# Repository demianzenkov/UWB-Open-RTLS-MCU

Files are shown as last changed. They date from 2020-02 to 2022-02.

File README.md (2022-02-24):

Source code for Open-RTLS nodes (anchor, tag) based on STM32 microcontrollers. 

Open-RTLS supports TWR and TDOA modes. 

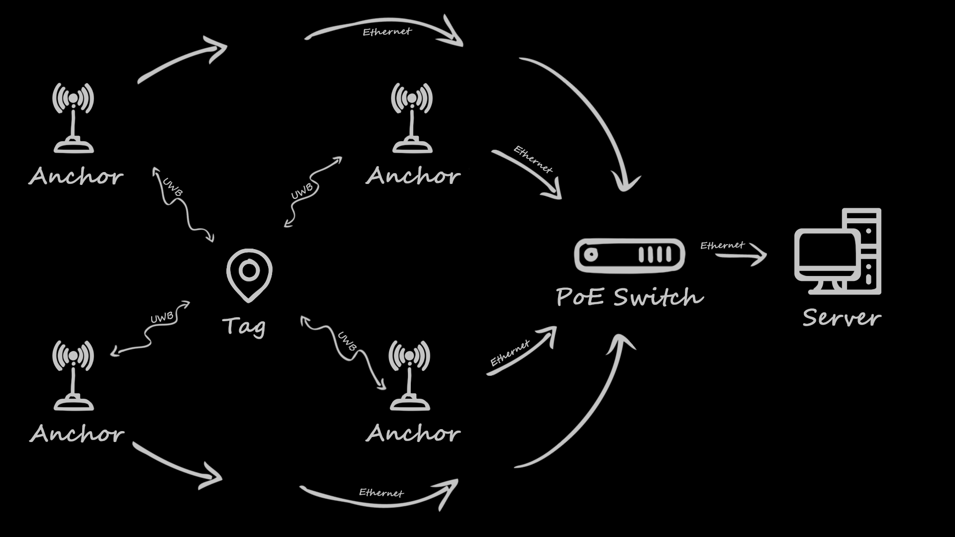
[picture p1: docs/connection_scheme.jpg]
connection_scheme
Communication scheme of RTLS units:

Anchor nodes are based on STM32F207 microcontrollers and have ethernet interface. Both anchors and tags have USB interface for connection with configuartion software.

To setup network and RTLS parameters of nodes use [Open-RTLS Configurator](https://github.com/DemianZ/UWB-Open-RTLS-Configurator).

##### Generate .c and .h proto files from .proto file using Nanopb:

```bash
pip install protobuf grpcio-tools
python proto/nanopb_generator.py -v proto/Settings.proto
```

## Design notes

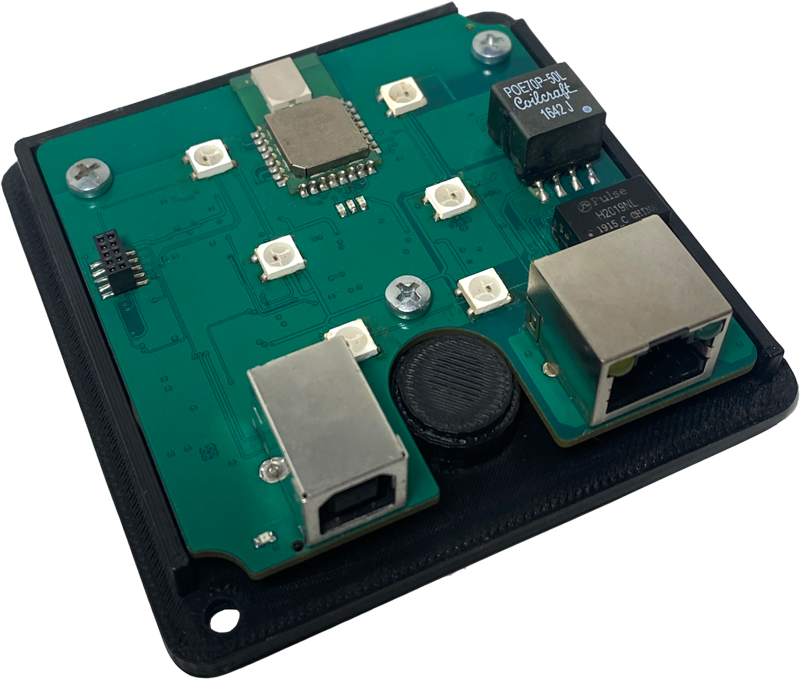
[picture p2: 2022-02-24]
hardware/anchor/Photos/anchor_no_cover.png

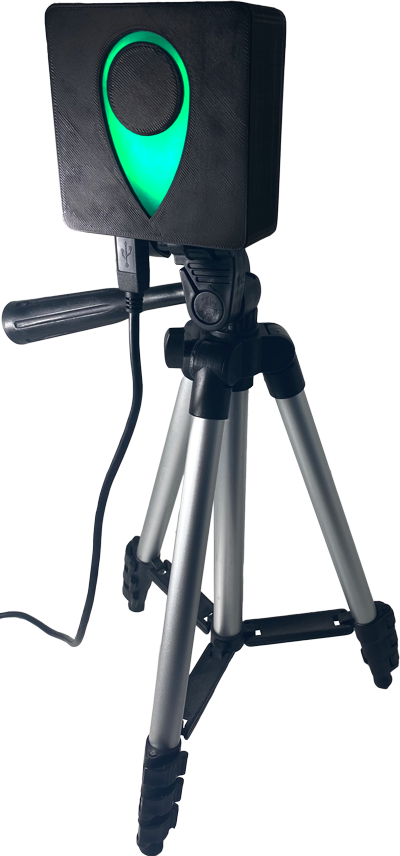
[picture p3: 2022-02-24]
hardware/anchor/Photos/anchor_shtativ.png

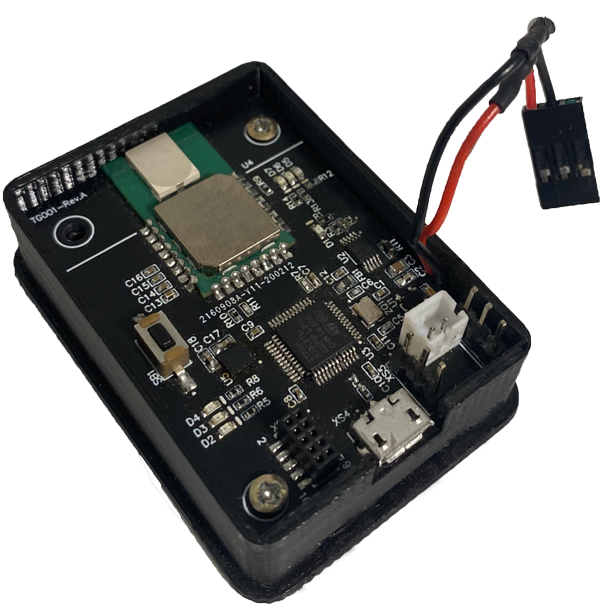
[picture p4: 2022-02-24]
hardware/anchor/Photos/tag_no_cover.png

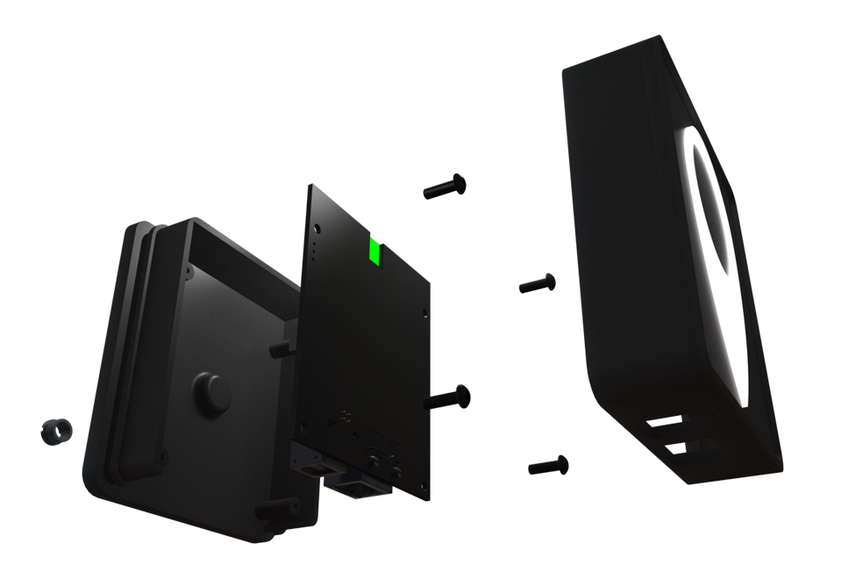
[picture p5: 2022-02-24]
hardware/anchor/Render/AN_01.png

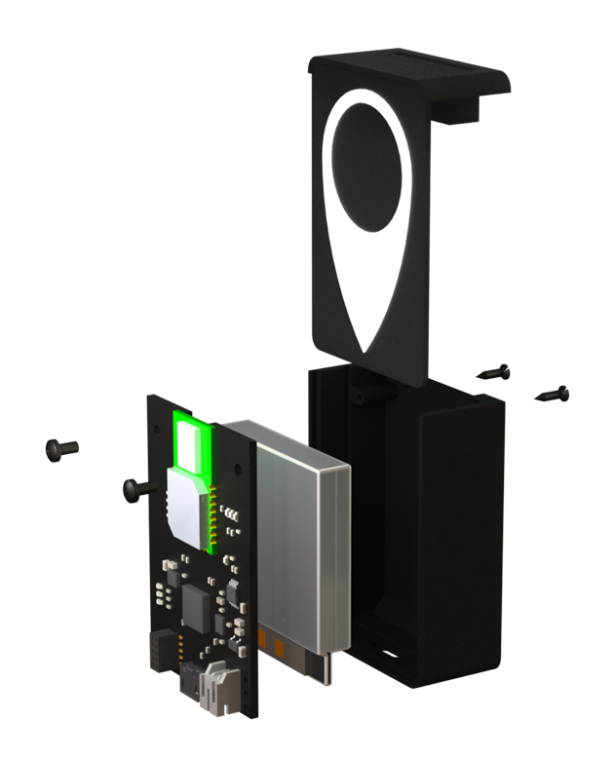
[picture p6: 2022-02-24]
hardware/anchor/Render/TG_02.png

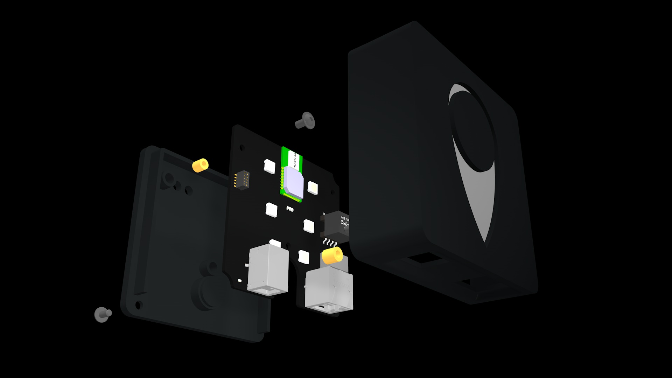
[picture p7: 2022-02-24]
hardware/anchor/Render/an_002.jpg

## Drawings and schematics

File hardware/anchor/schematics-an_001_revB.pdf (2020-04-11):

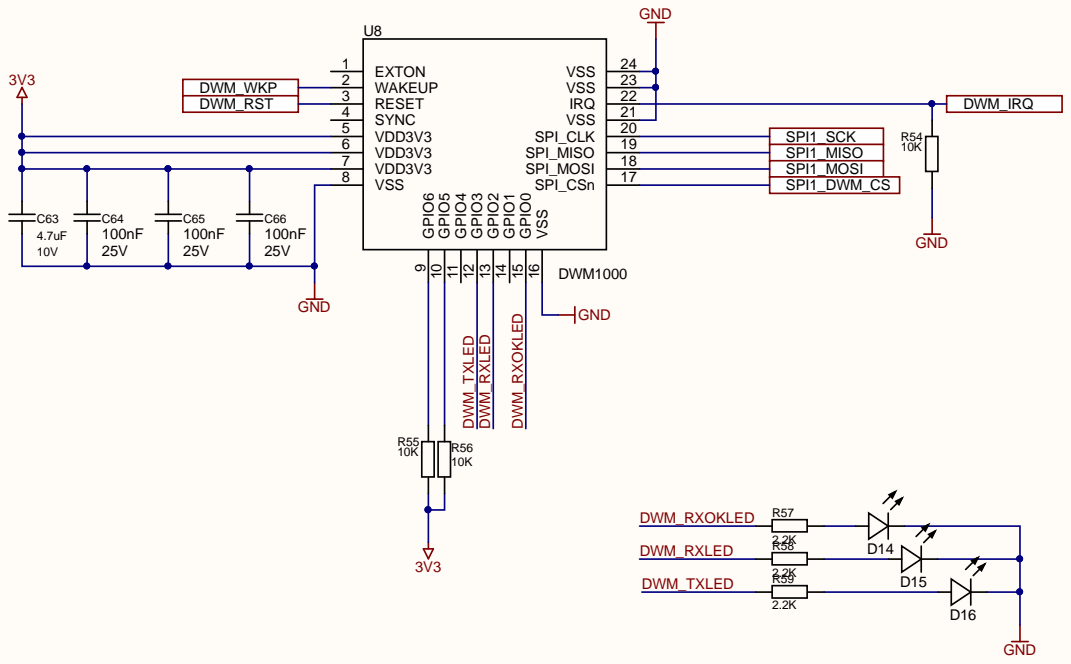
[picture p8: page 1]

VSS 16 SPI_CSn 17 SPI_MOSI 18 SPI_MISO 19 SPI_CLK 20 VSS 21 IRQ 22 VSS 23 VSS 24

VDD3V3 6

VSS 8

* Title | * * * * *

Size: A4 | Number: * | Revision: *
Date: 16.02.2020 Time: 14:38:03 | | Sheet * of *

\\Mac\Home\Documents\PROJECTS\UWB-RTLS\hw\AN-001_revB\Altium\dwm.SchDoc

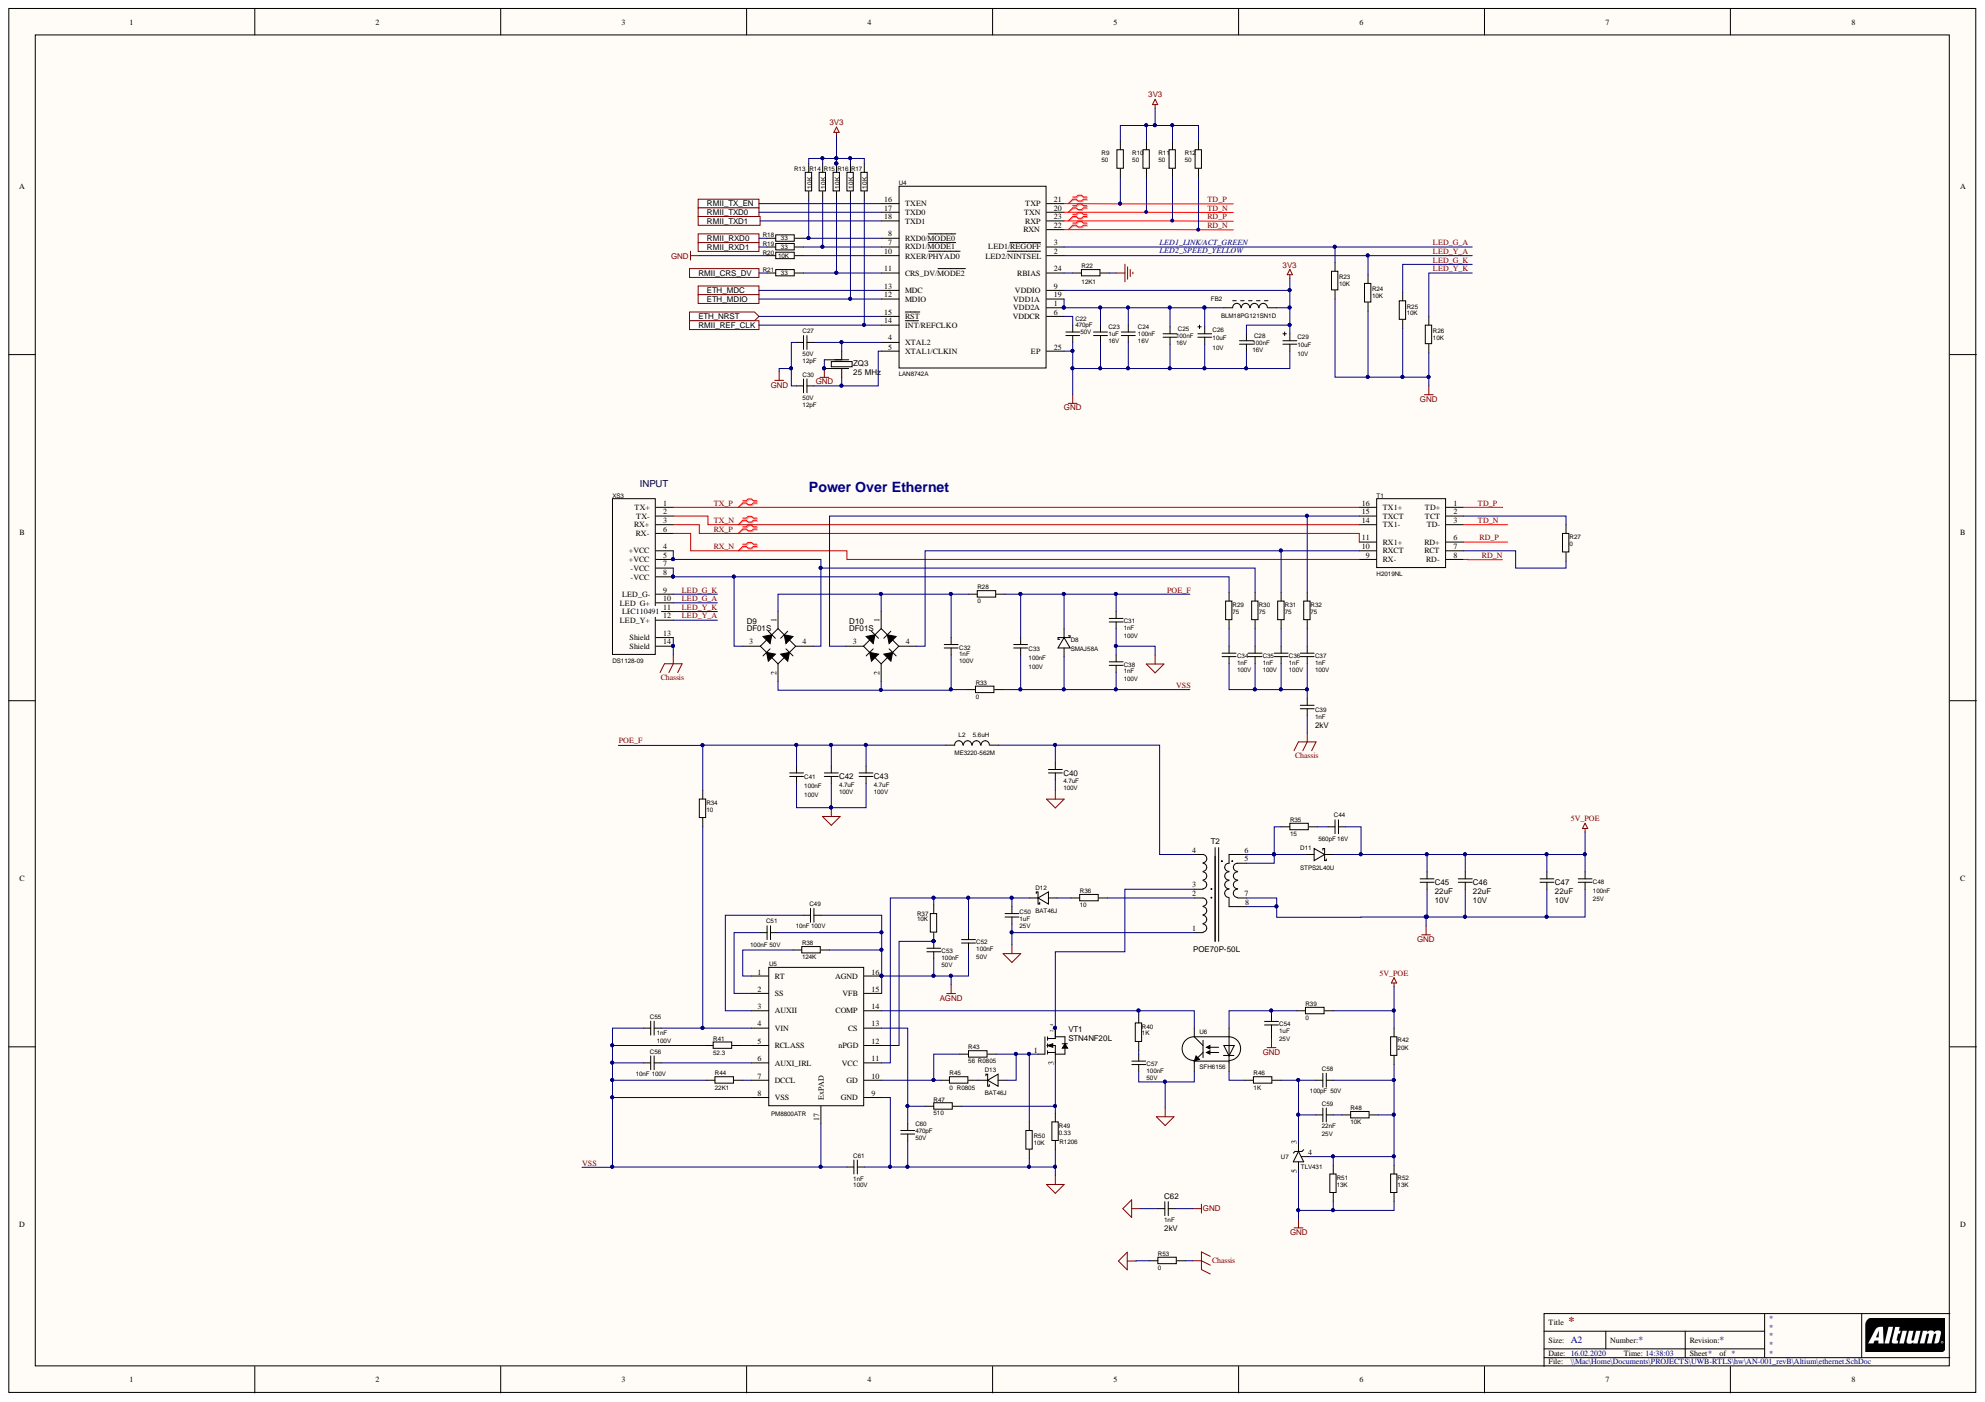
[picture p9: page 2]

Power Over Ethernet INPUT

TX1- 14 TXCT 15 TX1+ 16

Title

Size: A2 | Number: | Revision:

\\Mac\Home\Documents\PROJECTS\UWB-RTLS\hw\AN-001_revB\Altium\ethernet.SchDoc

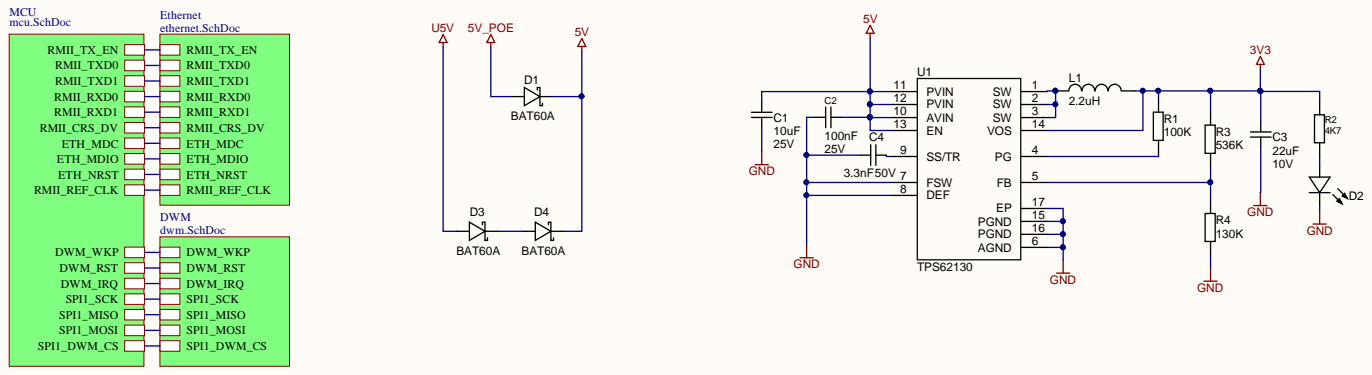
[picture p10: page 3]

Size: A4 | N umber: * | Rev i s i o n : *

6.0 2.2 T ime: : : | | Sheet o f

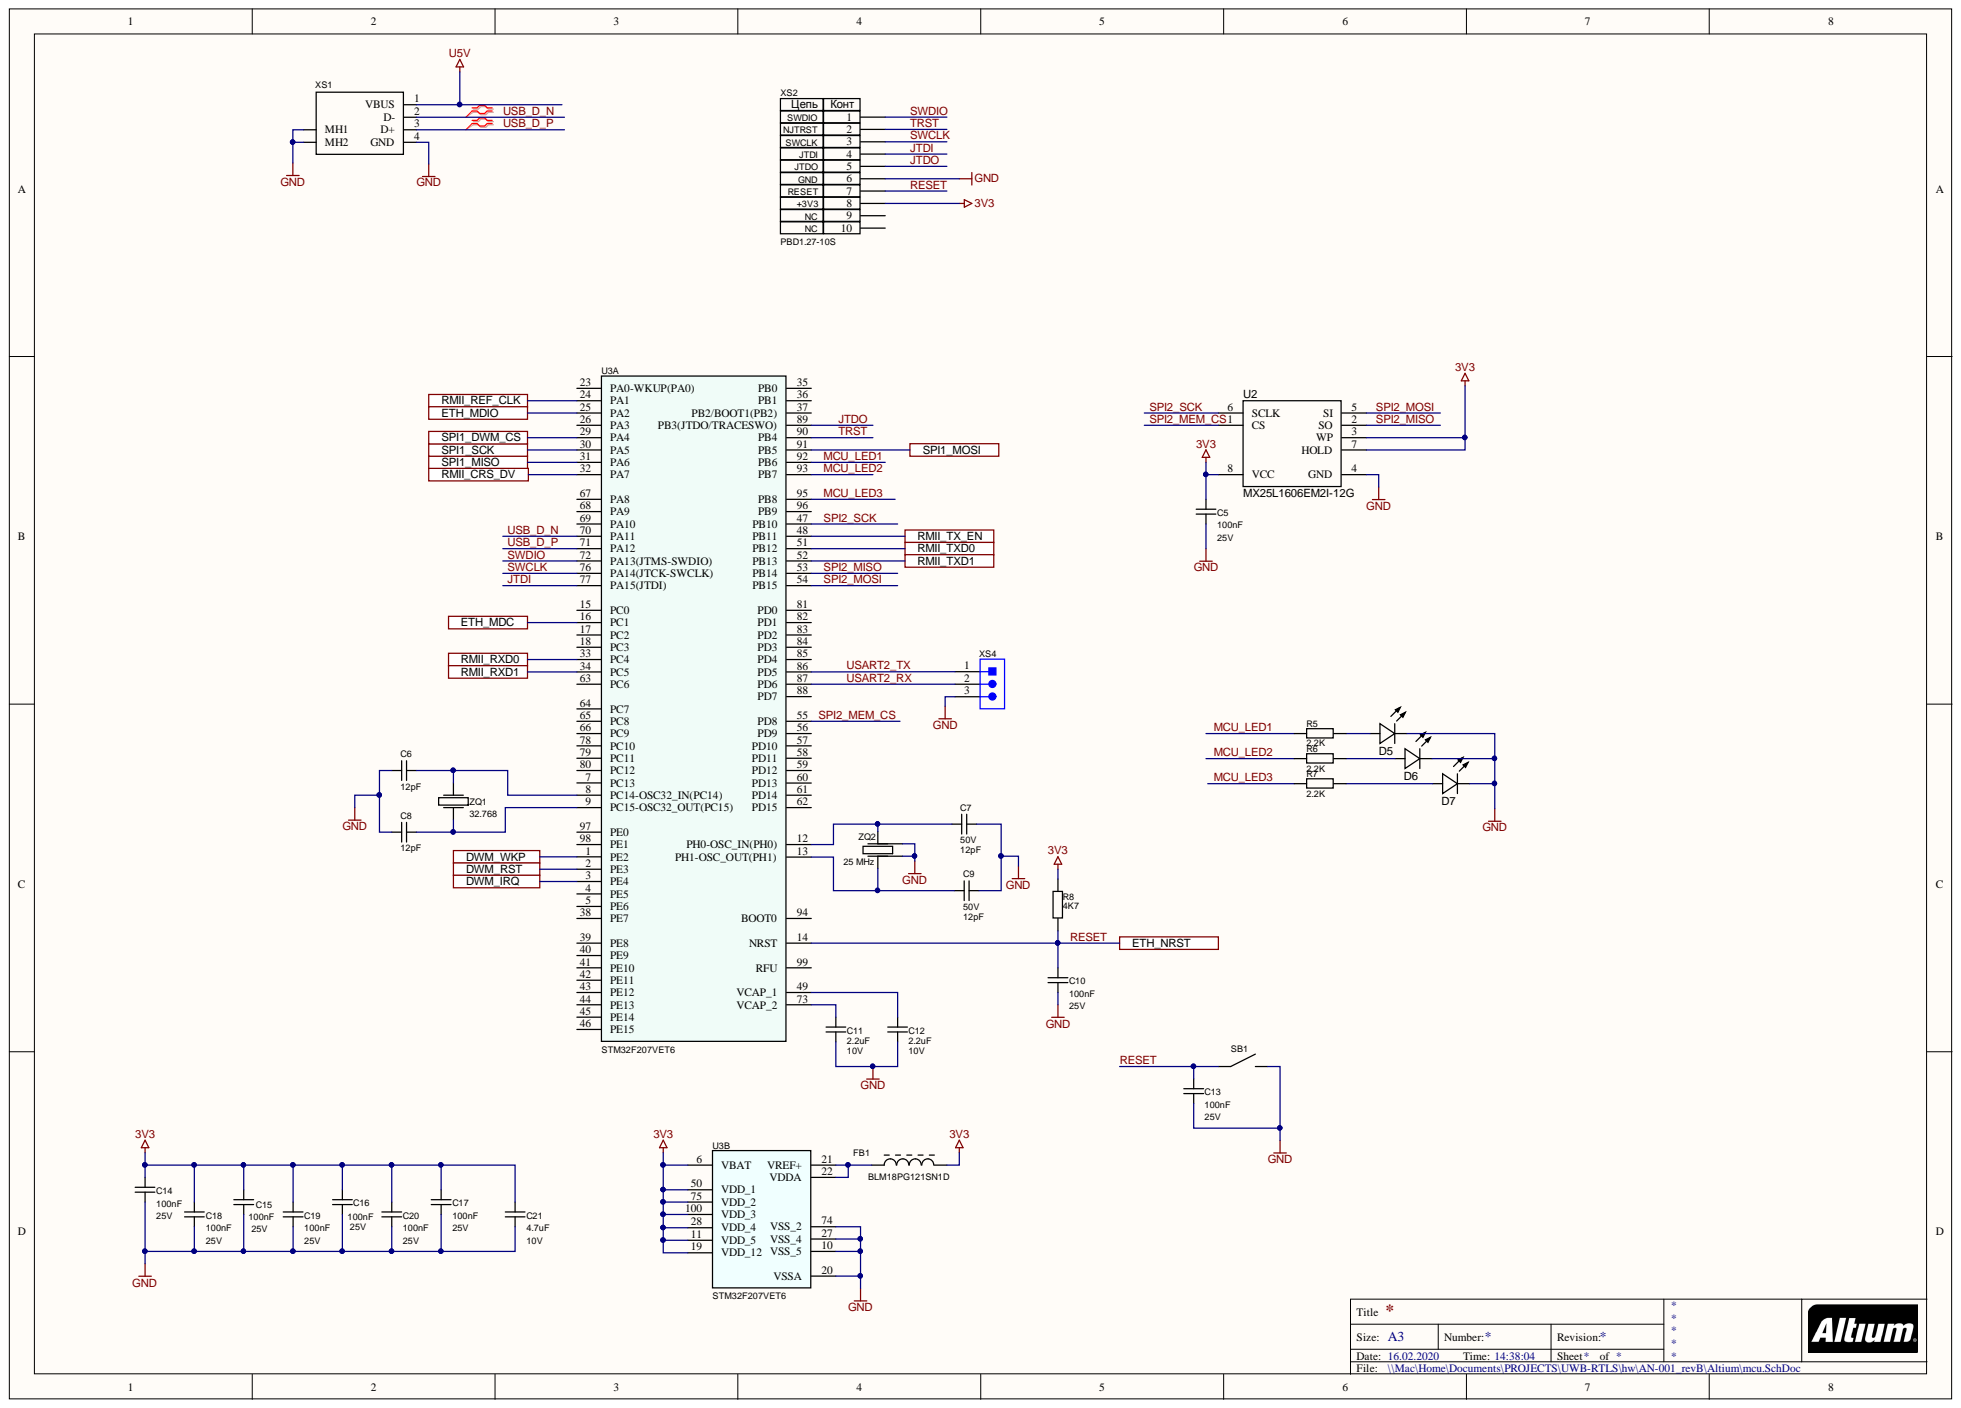
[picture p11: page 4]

SWDIO
NJTRST | 2
SWCLK | 3
JTDI | 4
JTDO | 5
GND | 6
RESET | 7
+3V3 | 8
NC | 9
NC | 10

SPI1_SCK | PA6 31 | SPI1_MOSI
SPI1_MISO | PA7 32

RMII_RXD0 | PC5 34
RMII_RXD1 | PC6 63 | USART2_RX 2

DWM_WKP | PE3 2 | 25 MHz

RESET | ETH_NRST

Title

Size: A3 | Number: | Revision:

\\Mac\Home\Documents\PROJECTS\UWB-RTLS\hw\AN-001_revB\Altium\mcu.SchDoc

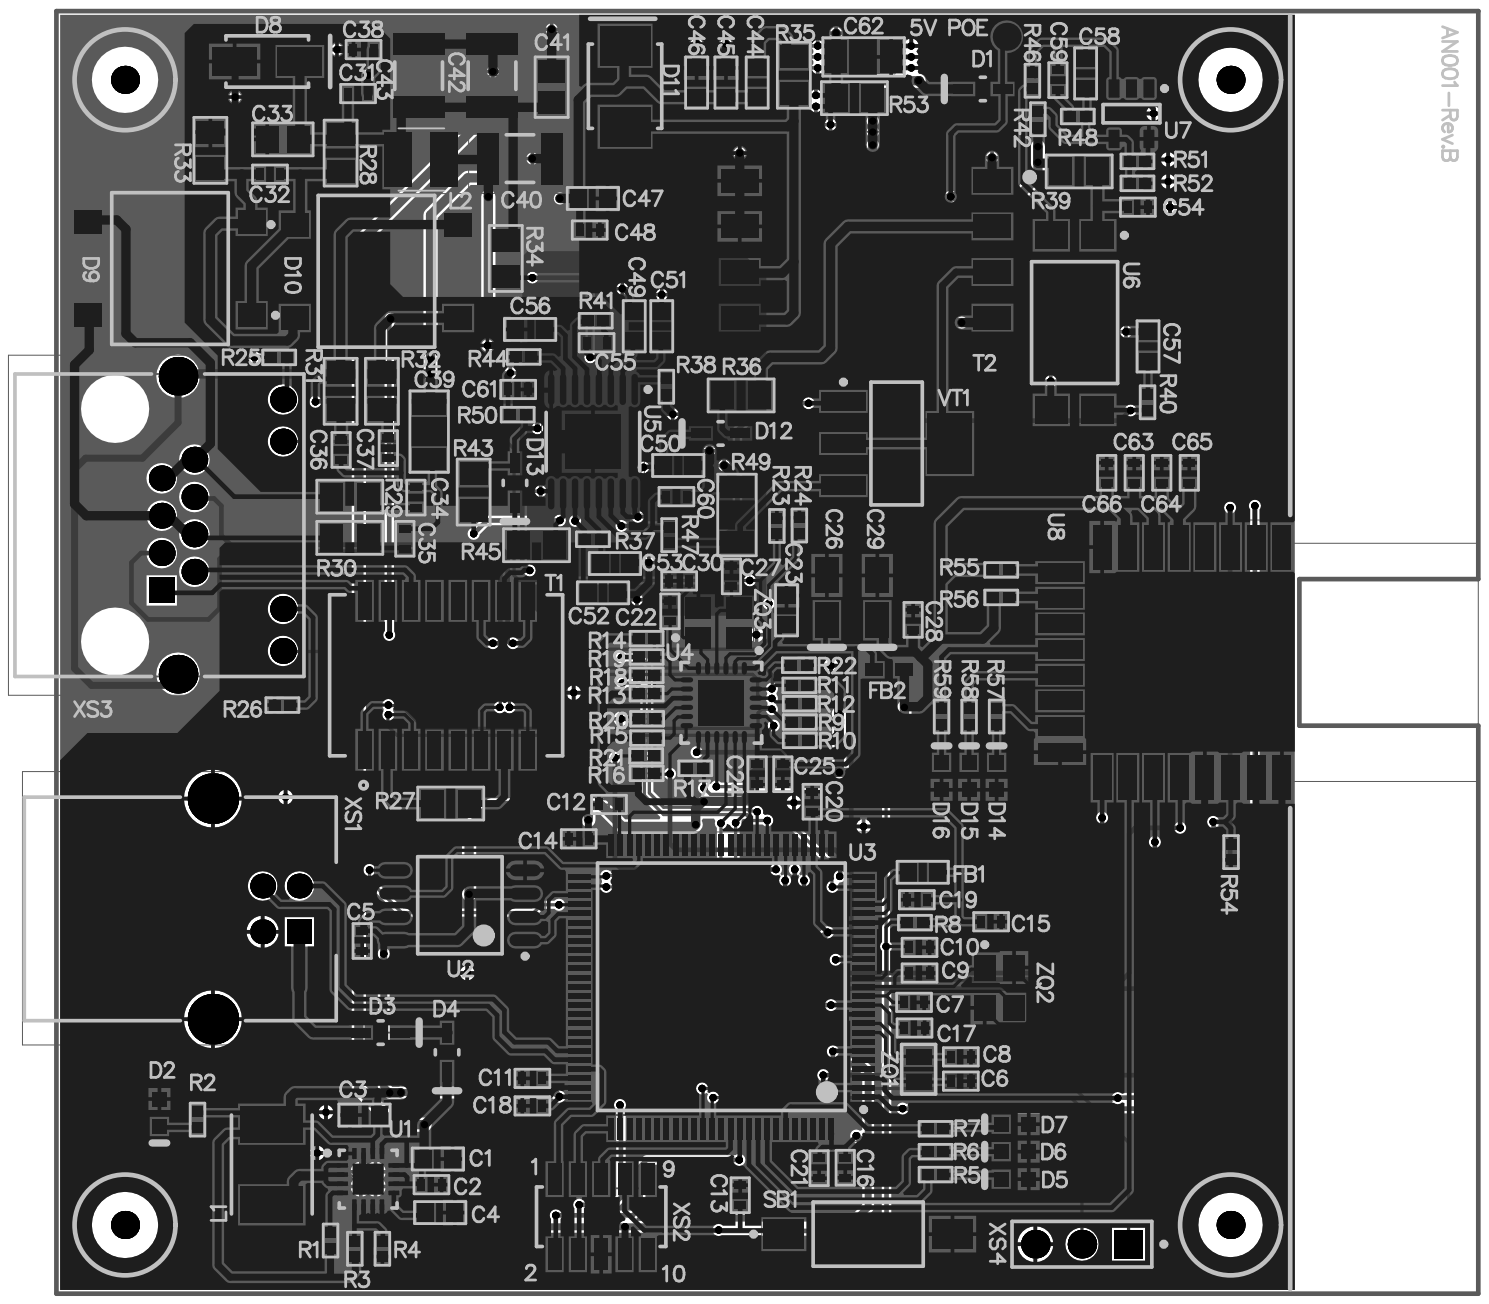
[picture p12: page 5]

Manufacturer Part Number | Designator | Quantity | Manufacturer | Supplier 1 | Supplier Part Number 1
GRM188R61E106KA73D | C1 | 1 | Murata | LCSC | C344022
GCM155R71E104KE02D | C2, C5, C10, C13, C14, | 15 | Murata | LCSC | C126527
GRM188R61A226ME15D | C3, C45, C46, C47 | 4 | Murata | LCSC | C84419
GRM155R71H332KA01D | C4 | 1 | Murata | LCSC | C85963
GJM1555C1H120FB01D | C6, C8 | 2 | Murata | LCSC | C161304
CC0402JRNPO9BN120 | C7, C9, C27, C30 | 4 | Yageo | LCSC | C106201
GRM155R61A225KE95D | C11, C12 | 2 | Murata | LCSC | C77002
GRM155R61A475KEAAD | C21, C63 | 2 | Murata | LCSC | C77004
GRM155R71H471JA01D | C22, C60 | 2 | Murata | LCSC | C415539
GRM155R61C105KA12D | C23 | 1 | Murata | LCSC | C77006
GCM155R71C104KA55D | C24, C25, C28 | 3 | Murata | LCSC | C85857
TPSA106K010R0900 | C26, C29 | 2 | Kyocera AVX | LCSC | C74423
GCM155R72A102KA37D | C31, C32, C34, C35, C36 | 9 | Murata | LCSC | C126538
GCM21BR72A104KA37L | C33, C41 | 2 | Murata | LCSC | C85866
GR431BR7LA102KW66L | C39, C62 | 2 | Murata | LCSC | C161353
C3225X7S2A475KT000N | C40, C42, C43 | 3 | TDK | LCSC | C342614
GRM155R71H561KA01D | C44 | 1 | Murata | LCSC | C162194
GCJ188R72A103KA01D | C49, C56 | 2 | Murata | LCSC | C354383
GCM188R71E105KA64D | C50 | 1 | Murata | LCSC | C85862
GCJ188R71H104KA12D | C51, C52, C53, C57 | 4 | Murata | LCSC | C161115
GRM155R61E105KA12D | C54 | 1 | Murata | LCSC | C77009
GRM1885C1H101JA01D | C58 | 1 | Murata | LCSC | C71664
GCM155R71E223KA55J | C59 | 1 | Murata | LCSC | C437448
BAT60JFILM | D1, D3, D4 | 3 | STMicroelectronics | LCSC | C133103
FC-DA1608HGK-572C | D2, D6 | 2 | Foshan NationStar | LCSC | C84264
FC-DA1608HRK-620D | D5, D14, D15, D16 | 4 | Foshan NationStar | LCSC | C84263
FC-DA1608BK-470H10 | D7 | 1 | Foshan NationStar | LCSC | C84266
SMAJ58A-TR | D8 | 1 | STMicroelectronics | LCSC | C132936
DF01S-T | D9, D10 | 2 | Diodes | LCSC | C110491
STPS2L40U | D11 | 1 | STMicroelectronics | LCSC | C169095
BAT46JFILM | D12, D13 | 2 | STMicroelectronics | LCSC | C111205
BLM18PG121SN1D | FB1, FB2 | 2 | Murata | LCSC | C14709
SPM4012T-2R2M | L1 | 1 | TDK | LCSC | C114774
ME3220-562MLC | L2 | 1 | Coilcraft | Coilcraft | ME3220-562MLC
RC0402FR-07100KL | R1 | 1 | YAGEO | LCSC | C60491
RC0402FR-074K7L | R2, R8 | 2 | YAGEO | LCSC | C105871
RC0402FR-07536KL | R3 | 1 | YAGEO | LCSC | C327337
RC0402FR-07130KL | R4 | 1 | YAGEO | LCSC | C93946
RC0402FR-072K2L | R5, R6, R7, R57, R58, R | 6 | YAGEO | LCSC | C114762
AC0402JR-0750RL | R9, R10, R11, R12 | 4 | YAGEO | LCSC | C227387
RC0402FR-0710KL | R13, R14, R15, R16, R17 | 16 | YAGEO | LC SC | C60490
RC0402FR-0733RL | R18, R19, R21 | 3 | YAGEO | LCSC | C138002
RC0402FR-0712K1L | R22 | 1 | YAGEO | LCSC | C132157
RC0805JR-070RL | R27, R28, R33, R39, R45 | 6 | YAGEO | LCSC | C96345
AC0805FR-0775RL | R29, R30, R31, R32 | 4 | YAGEO | LCSC | C228992
RC0805JR-0710RL | R34, R36 | 2 | YAGEO | LCSC | C137478
AC0805JR-0715RL | R35 | 1 | YAGEO | LCSC | C229084
AC0402FR-07124KL | R38 | 1 | YAGEO | LCSC | C226764
RC0402FR-071KL | R40, R46 | 2 | YAGEO | LCSC | C106235
AC0402FR-0752R3L | R41 | 1 | YAGEO | LCSC | C227131
RC0402JR-0720KL | R42 | 1 | YAGEO | LCSC | C137902
RC0805JR-0756KL | R43 | 1 | YAGEO | LCSC | C137420
RC0402FR-0722K1L | R44 | 1 | YAGEO | LCSC | C163478
RC0402JR-07510RL | R47 | 1 | YAGEO | LCSC | C137860
1206W4F330LT5E | R49 | 1 | UNI-ROYAL(UniroyaLC SC
RC0402FR-0713KL | R51, R52 | 2 | YAGEO | LCSC | C138057
| SB1 | 1
H2019NL | T1 | 1 | Pulse Electronics | LCSC | C110250
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

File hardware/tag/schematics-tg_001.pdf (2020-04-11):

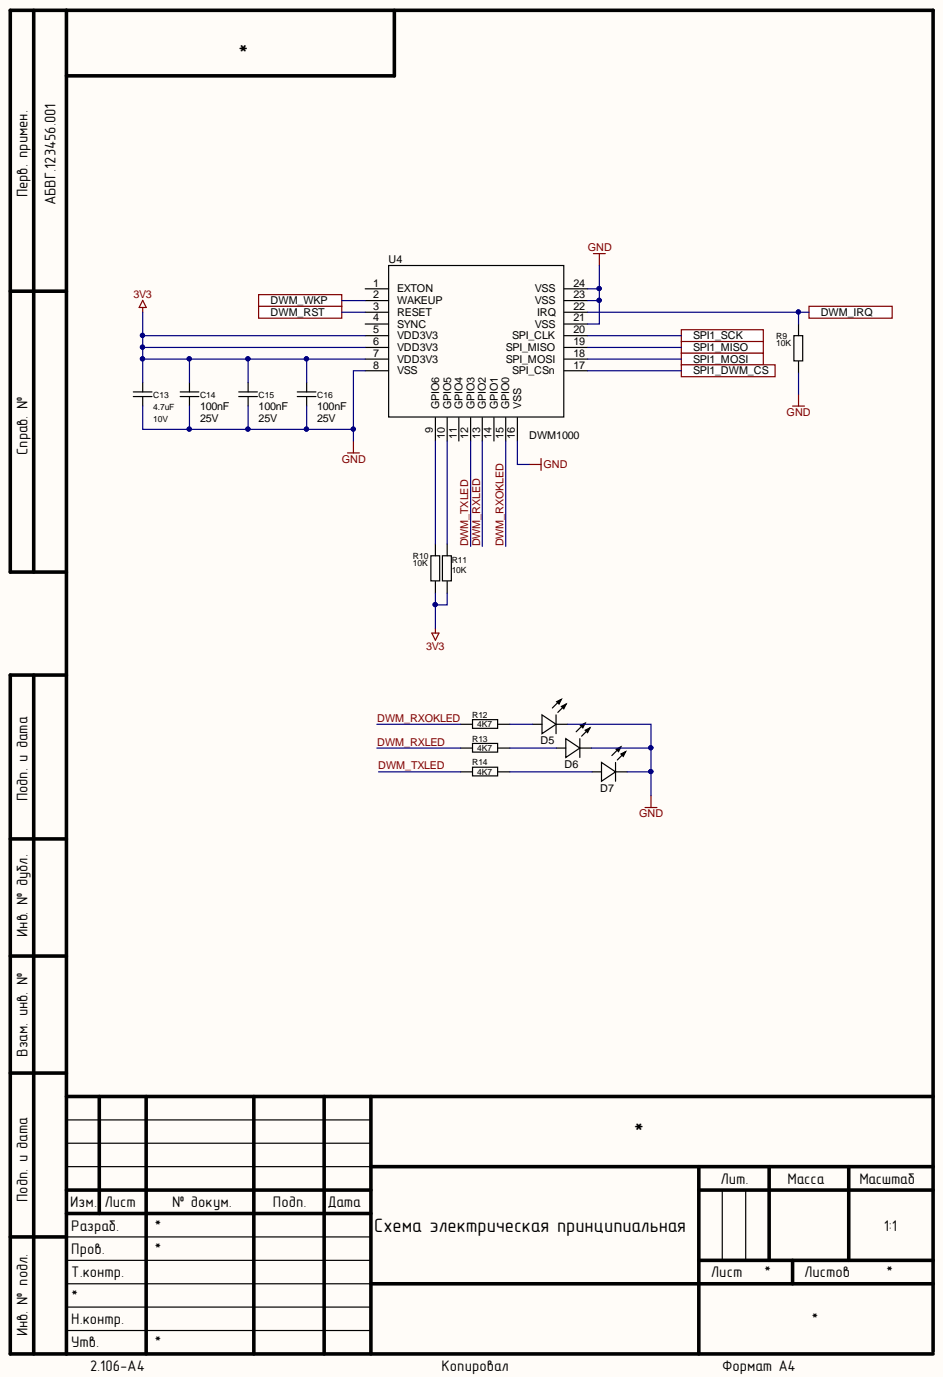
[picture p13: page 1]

Инв. № подл. Инв. № дубл. Подп. и дата Взам. инв. № Подп. и дата Перв. примен. Справ. №

VSS 16 SPI_CSn 17 SPI_MOSI 18 SPI_MISO 19 SPI_CLK 20 VSS 21 IRQ 22 VSS 23 VSS 24

DWM_RST | RESET 3 SYNC 4 | DWM_IRQ

VDD3V3 6 | SPI1_SCK
VDD3V3 7 | SPI1_MISO
VSS 8 | SPI1_MOSI

Схема электрическая принципиальная | Лит. | Масса | Масштаб

Изм. | Лист | № докум. | Подп. | Дата | | | | | 1:1
Разраб. | | *
Пров. | *
Т.контр. | | | | | Лист * | Листов *

Н.контр.
Утв.

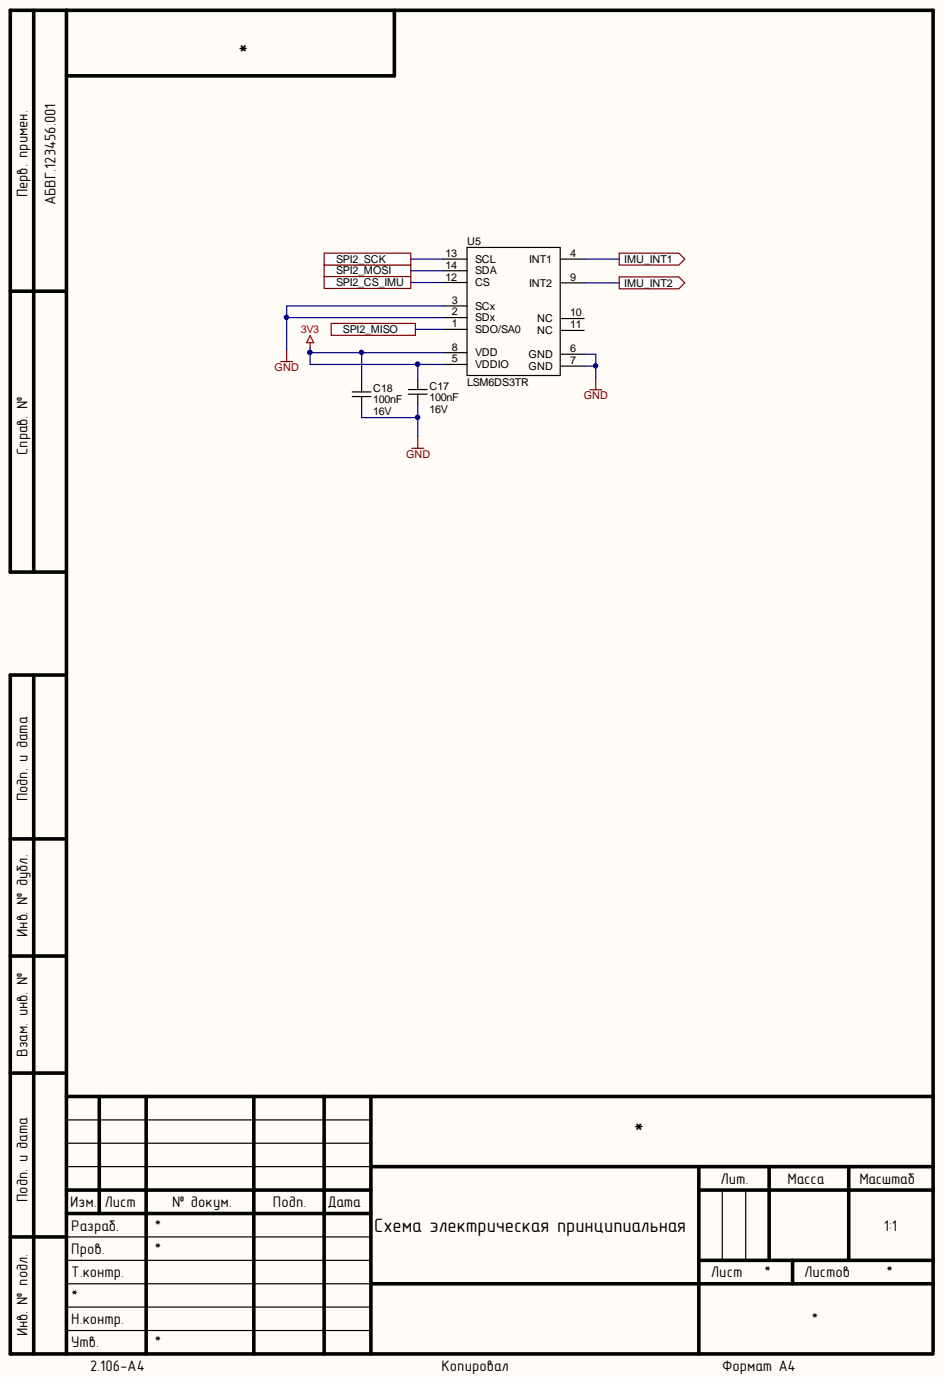
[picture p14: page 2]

Инв. № подл. Инв. № дубл. Подп. и дата Взам. инв. № Подп. и дата Перв. примен. Справ. №

SPI2_SCK | SDA 14
SPI2_MOSI | CS 12
SPI2_CS_IMU | SCx 3

Схема электрическая принципиальная | Лит. | Масса | Масштаб

Изм. | Лист | № докум. | Подп. | Дата | | | | | 1:1
Разраб. | | *
Пров. | *

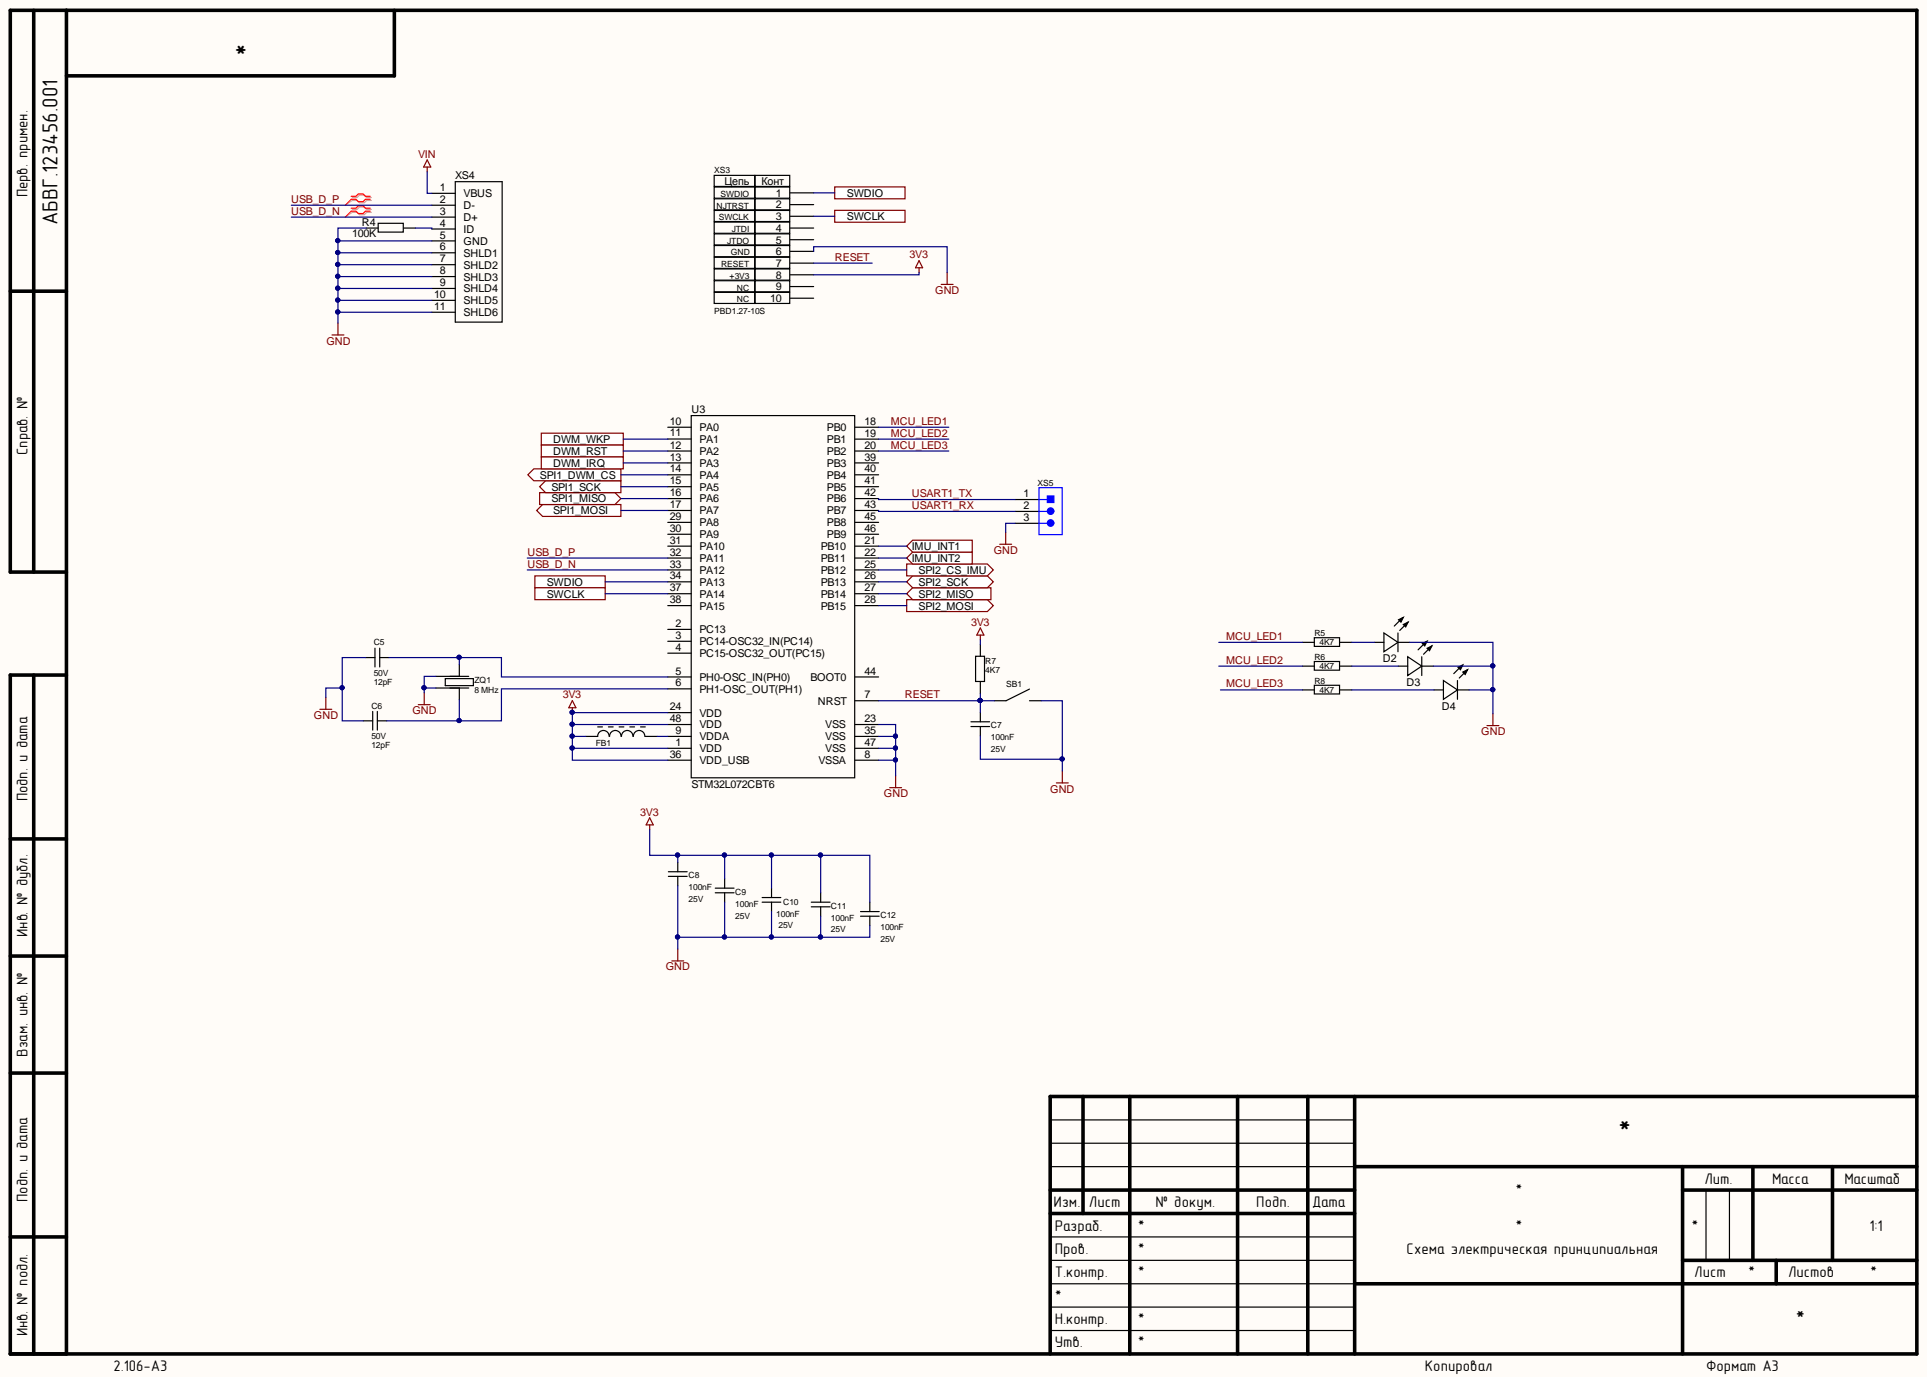
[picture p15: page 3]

Инв. № подл. Инв. № дубл. Подп. и дата Взам. инв. № Подп. и дата Перв. примен. Справ. №

NJTRST | 2
SWCLK | 3 | SWCLK

ZQ1 | PH1-OSC_OUT(PH1) 6
8 MHz 3V3 | VDD 24

VDD 48

* * Схема электрическая принципиальная | Лит. | Масса | Масштаб

Изм. | Лист | № докум. | Подп. | Дата | | * | | | 1:1
Разраб. | | *
Пров. | | *

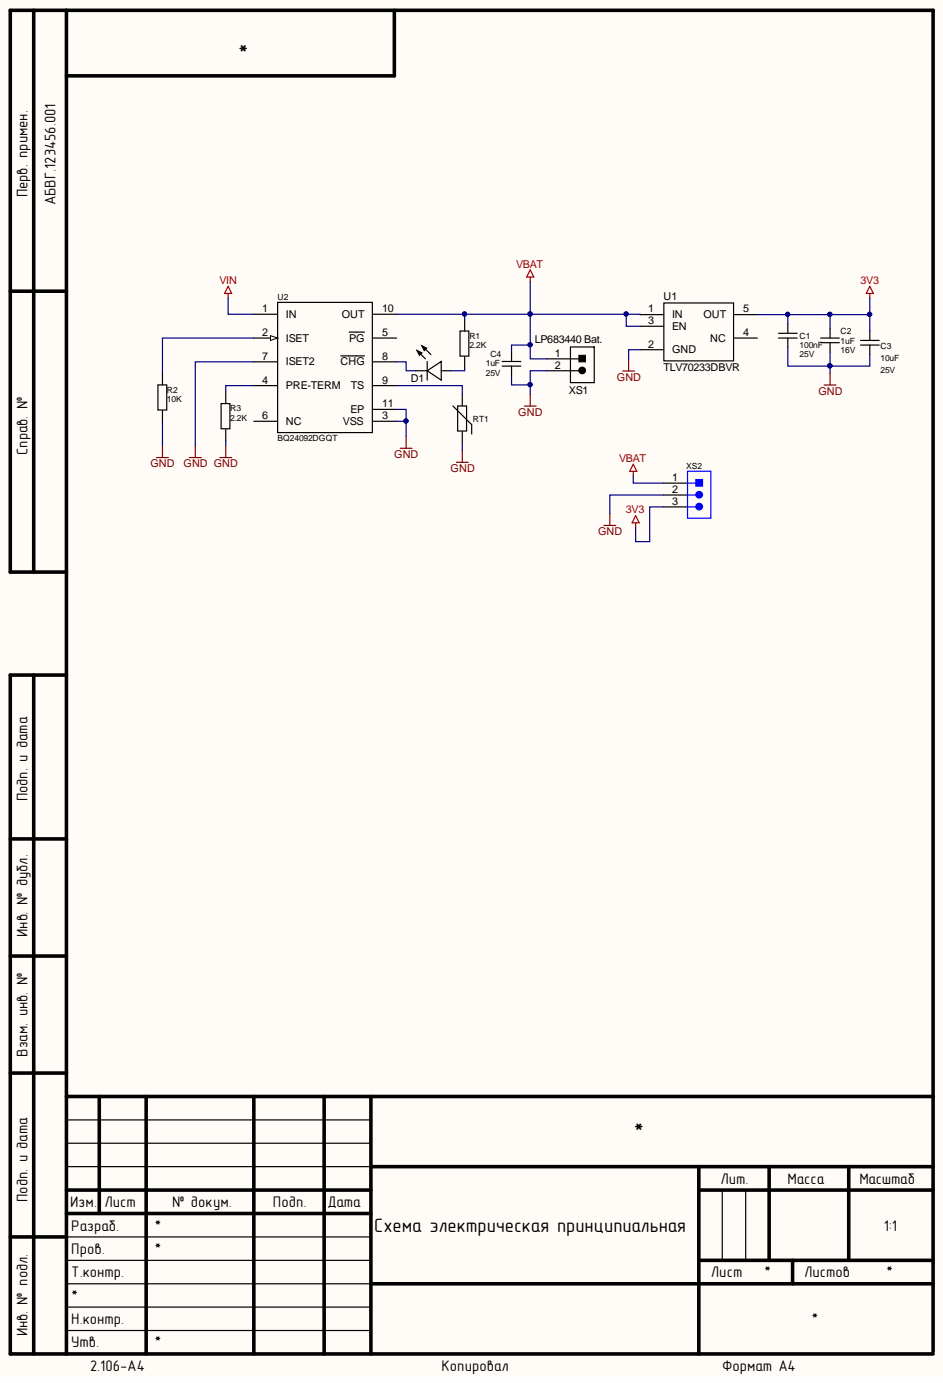
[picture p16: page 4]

Инв. № подл. Инв. № дубл. Подп. и дата Взам. инв. № Подп. и дата Перв. примен. Справ. №

Схем а электрическая принципиальная | Лит . | Масса | Масш таб

Изм . | Лист | № докум . | Подп . | Дат а | | | | | 1: 1
Разраб . | | *
Пров . | *
Т .конт р . | | | | | Лист | Листов

Н .конт р .
Ут в .

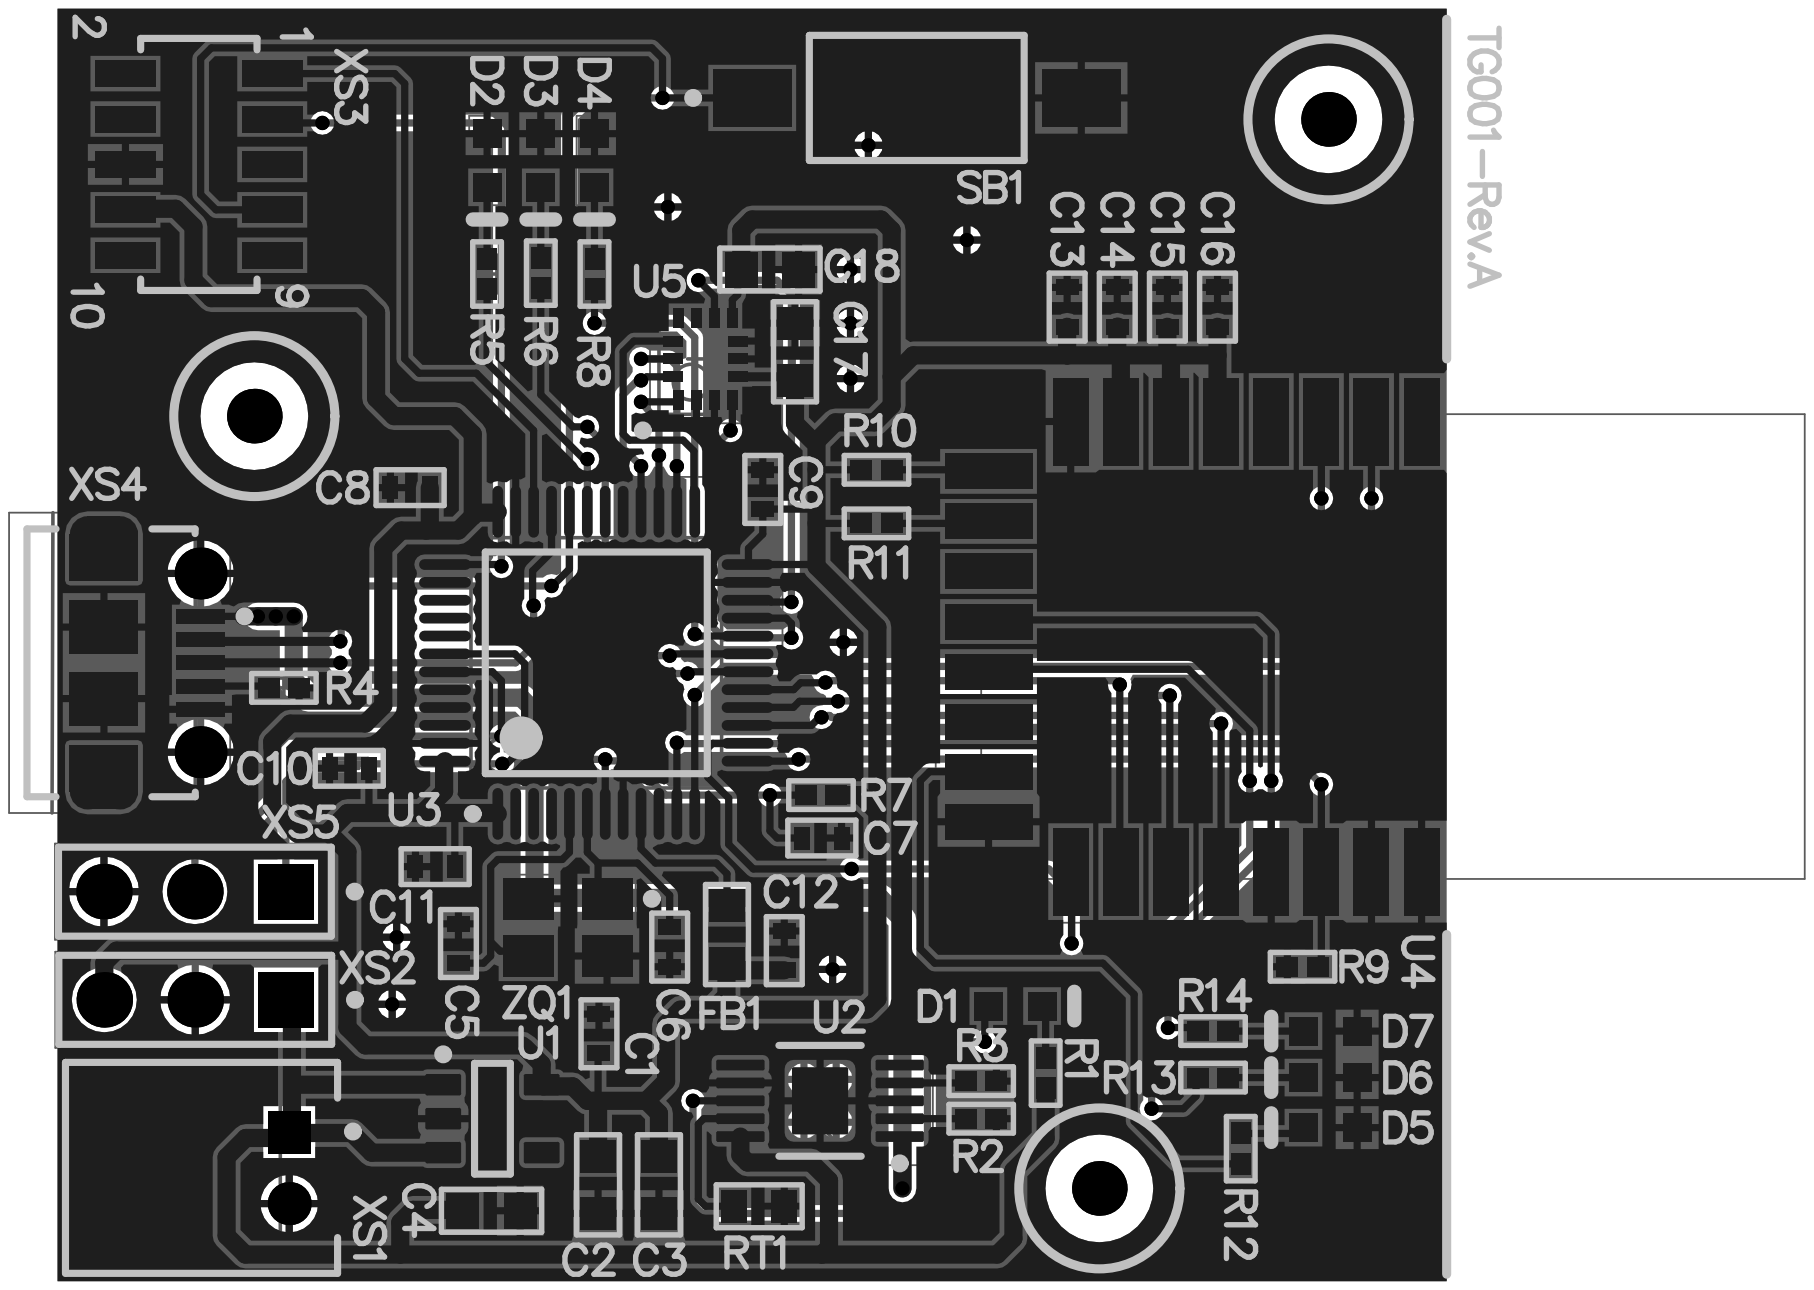
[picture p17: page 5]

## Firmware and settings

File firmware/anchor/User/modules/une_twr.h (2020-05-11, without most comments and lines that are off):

#define _UNE_TWR
#include "prj_defs.h"
#include "dwm1000.h"
#define UUS_TO_DWT_TIME 65536
#define POLL_RX_TO_RESP_TX_DLY_UUS 2750
#define RESP_TX_TO_FINAL_RX_DLY_UUS 500		//500
#define FINAL_RX_TIMEOUT_UUS 3700
#define POLL_TX_TO_RESP_RX_DLY_UUS 1000 //300 // 1000 - critical minimum value
#define RESP_RX_TIMEOUT_UUS 3700 //2700  //3700 works	// Receive response timeout. NOTE 5
#define RESP_RX_TO_FINAL_TX_DLY_UUS 3000
#define PRE_TIMEOUT 8 			// Preamble tomeout. NOTE 6
#define POLL_MSG_SIZE	10
#define RESP_MSG_SIZE	12
#define FINAL_MSG_SIZE	29
#define DW_MSG_PREAMBLE_LEN	4
#define DEFAULT_TAG_ID		0x01
#define DEFAULT_ANCHOR_ID	0x01
#define START_POLL_N_H	0
#define START_POLL_N_L	0
#define START_RESP_N_H	0
#define START_RESP_N_L	0
#define START_FINAL_N_H	0
#define START_FINAL_N_L	0
#define MSG_TS_LEN 	5
#define FINAL_MSG_POLL_TX_TS_IDX	12
#define FINAL_MSG_RESP_RX_TS_IDX	17
#define FINAL_MSG_FINAL_TX_TS_IDX	22
#define MSG_TAG_IDX		4
#define MSG_AN_IDX		5
#define MSG_POLL_H_IDX		6
#define MSG_POLL_L_IDX		7
#define MSG_RESP_H_IDX		8
#define MSG_RESP_L_IDX		9
#define MSG_FINAL_H_IDX		10
#define MSG_FINAL_L_IDX		11
#define SPEED_OF_LIGHT 299702547	// metres per second
class UNE_TWR {
public:
  UNE_TWR(DWM1000 * dwm);
  ~UNE_TWR();
  static void initDWM();
  S08 twrResponderLoop();
  S08 twrInitiatorLoop(U08 an_id);	// use anchor in tag mode for calibration
  static void final_msg_get_ts(uint8 *ts_field, uint64 *ts);
  static void final_msg_set_ts(uint8 *ts_field, uint64 ts);
private:
  DWM1000 * dwm;
  U16 poll_frame_seq_nb;	// Tag
  U16 resp_frame_seq_nb;	// Anchor
  U16 final_frame_seq_nb;	// Tag
  U64 poll_rx_ts; 	// anchor(responder)
  U64 resp_tx_ts;	// anchor(responder)
  U64 final_rx_ts;	// anchor(responder)
  U64 poll_tx_ts;	// tag(initiator)
  U64 resp_rx_ts;	// tag(initiator)
  U64 final_tx_time;	// tag(initiator)
  U64 final_tx_ts;	// tag(initiator)
  U08 tag_id;		// anchor(initiator)
  double tof;		// anchor(initiator)
  float distance;	// anchor(initiator)
  U08 poll_msg[POLL_MSG_SIZE] = {'T', 'W', 'R', 'P',
			DEFAULT_TAG_ID,
			DEFAULT_ANCHOR_ID,
			START_POLL_N_H,
			START_POLL_N_L,
  			0, 0};		// CRC
  U08 resp_msg[RESP_MSG_SIZE] = {'T', 'W', 'R', 'R',
			DEFAULT_TAG_ID,
			DEFAULT_ANCHOR_ID,
			START_POLL_N_H,
			START_POLL_N_L,
			START_RESP_N_H,
			START_RESP_N_L,
  			0, 0};		// CRC
  U08 final_msg[FINAL_MSG_SIZE] = {'T', 'W', 'R', 'F',
			DEFAULT_TAG_ID,
			DEFAULT_ANCHOR_ID,
			START_POLL_N_H,
			START_POLL_N_L,
			START_RESP_N_H,
			START_RESP_N_L,
			START_FINAL_N_H,
			START_FINAL_N_L,
			0,0,0,0,0,	// POLL TX
			0,0,0,0,0,	// RESP RX
			0,0,0,0,0,	// FINAL TX
  			0, 0};		//
};

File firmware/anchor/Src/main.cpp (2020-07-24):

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

/* Includes ------------------------------------------------------------------*/
#include "main.h"
#include "cmsis_os.h"
#include "lwip.h"
#include "usb_device.h"

#include "usbd_cdc_if.h"
#include "bsp_os.h"
#include "bsp_spi.h"
    
#include "tsk_udp_client.h"
//#include "tsk_tcp_client.h"
#include "tsk_dwm.h"
#include "tsk_usb.h"
#include "tsk_network.h"
#include "tsk_event.h"
#include "indication.h"
#include "mx25.h"
#include "settings.h"




SPI_HandleTypeDef hspi1;
SPI_HandleTypeDef hspi2;

TIM_HandleTypeDef htim1;
TIM_HandleTypeDef htim6;
DMA_HandleTypeDef hdma_tim1_ch1;

osThreadId initTaskHandle;
/* USER CODE BEGIN PV */
BSP_SPI spi2(&hspi2, 2);


volatile uint32_t us_tick = 0;
/* USER CODE END PV */

void SystemClock_Config(void);
static void MX_GPIO_Init(void);
static void MX_DMA_Init(void);
static void MX_SPI1_Init(void);
static void MX_SPI2_Init(void);
static void MX_TIM6_Init(void);
static void MX_TIM1_Init(void);
void initTask(void const * argument);

/**
  * @brief  The application entry point.
  * @retval int
  */
int main(void)
{
  /* MCU Configuration--------------------------------------------------------*/

  /* Reset of all peripherals, Initializes the Flash interface and the Systick. */
  HAL_Init();

  /* Configure the system clock */
  SystemClock_Config();

  /* Initialize all configured peripherals */
  MX_GPIO_Init();
  MX_DMA_Init();
  MX_SPI1_Init();
  MX_SPI2_Init();
  MX_TIM6_Init();
  MX_TIM1_Init();

  mx25.init(&spi2);
  settings.init();
  
  indication.init();
  indication.pixelToDMA(0, 128, 0, 0);
  indication.pixelToDMA(0, 128, 0, 1);
  indication.pixelToDMA(0, 128, 0, 2);
  indication.pixelToDMA(0, 128, 0, 3);
  indication.pixelToDMA(0, 128, 0, 4);
  indication.pixelToDMA(0, 128, 0, 5);
    
  
  /* init code for USB_DEVICE */
  MX_USB_DEVICE_Init();
  
  /* init code for LWIP */
  MX_LWIP_Init();
    
  /* Create the thread(s) */
  tskUdpClient.createTask();
  tskDWM.createTask();
  tskUSB.createTask();
  tskNetwork.createTask();
  tskEvent.createTask();
  
  osThreadDef(initTask, initTask, osPriorityNormal, 0, 1024);
  initTaskHandle = osThreadCreate(osThread(initTask), NULL);
  
  /* Start scheduler */
  osKernelStart();
  
  /* We should never get here as control is now taken by the scheduler */

  /* Infinite loop */
  while (1)
  {
  }
}

/* USER CODE END Header_StartDefaultTask */
void initTask(void const * argument)
{ 
  xSemaphoreGive(tskDWM.xSemUSBReady);
  
  if (mx25.detect() != TRUE)
  {
    for(;;)
    {
      osDelay(1000);
//      HAL_GPIO_WritePin(LED2_GPIO_Port, LED2_Pin, GPIO_PIN_RESET);
      osDelay(1000);
//      HAL_GPIO_WritePin(LED2_GPIO_Port, LED2_Pin, GPIO_PIN_SET); 
    }
  }
  /* Infinite loop */
  for(;;)
  {
    osDelay(1000);
//    HAL_GPIO_WritePin(LED1_GPIO_Port, LED1_Pin, GPIO_PIN_RESET);
    osDelay(1000);
//    HAL_GPIO_WritePin(LED1_GPIO_Port, LED1_Pin, GPIO_PIN_SET); 
  }
}

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


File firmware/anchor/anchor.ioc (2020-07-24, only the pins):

Mcu.UserName=STM32F207VETx
PA1.Signal=ETH_REF_CLK
PA11.Signal=USB_OTG_FS_DM
PA12.Signal=USB_OTG_FS_DP
PA13.Signal=SYS_JTMS-SWDIO
PA14.Signal=SYS_JTCK-SWCLK
PA15.Signal=SYS_JTDI
PA2.Signal=ETH_MDIO
PA4.GPIO_Label=DW_NSS
PA4.Signal=GPIO_Output
PA5.GPIO_Label=DW_SCK
PA5.Signal=SPI1_SCK
PA6.GPIO_Label=DW_MISO
PA6.Signal=SPI1_MISO
PA7.Signal=ETH_CRS_DV
PA8.GPIO_Label=LED_DIN
PA8.Signal=S_TIM1_CH1
PB10.GPIO_Label=FLASH_SCK
PB10.Signal=SPI2_SCK
PB11.Signal=ETH_TX_EN
PB12.Signal=ETH_TXD0
PB13.Signal=ETH_TXD1
PB14.GPIO_Label=FLASH_MISO
PB14.Signal=SPI2_MISO
PB15.GPIO_Label=FLASH_MOSI
PB15.Signal=SPI2_MOSI
PB3.Signal=SYS_JTDO-SWO
PB4.Signal=SYS_JTRST
PB5.GPIO_Label=DW_MOSI
PB5.Signal=SPI1_MOSI
PC1.Signal=ETH_MDC
PC14-OSC32_IN.Signal=RCC_OSC32_IN
PC15-OSC32_OUT.Signal=RCC_OSC32_OUT
PC4.Signal=ETH_RXD0
PC5.Signal=ETH_RXD1
PD1.GPIO_Label=LED_VDD
PD1.Signal=GPIO_Output
PD8.GPIO_Label=FLASH_CS
PD8.Signal=GPIO_Output
PE2.GPIO_Label=DW_WUP
PE2.Signal=GPIO_Output
PE3.GPIO_Label=DW_RESET
PE3.Signal=GPXTI3
PE4.GPIO_Label=DW_IRQn
PE4.Signal=GPXTI4
PH0-OSC_IN.Signal=RCC_OSC_IN
PH1-OSC_OUT.Signal=RCC_OSC_OUT

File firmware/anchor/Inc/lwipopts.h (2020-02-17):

/**
  ******************************************************************************
  * File Name          : lwipopts.h
  * Description        : This file overrides LwIP stack default configuration
  *                      done in opt.h file.
  ******************************************************************************
  * @attention
  *
  * <h2><center>&copy; Copyright (c) 2020 STMicroelectronics.
  * All rights reserved.</center></h2>
  *
  * This software component is licensed by ST under Ultimate Liberty license
  * SLA0044, the "License"; You may not use this file except in compliance with
  * the License. You may obtain a copy of the License at:
  *                             www.st.com/SLA0044
  *
  ******************************************************************************
  */
 
/* Define to prevent recursive inclusion --------------------------------------*/
#ifndef __LWIPOPTS__H__
#define __LWIPOPTS__H__

#include "main.h"

/*-----------------------------------------------------------------------------*/
/* Current version of LwIP supported by CubeMx: 2.0.3 -*/
/*-----------------------------------------------------------------------------*/

/* Within 'USER CODE' section, code will be kept by default at each generation */
#ifdef __cplusplus
 extern "C" {
#endif

/* STM32CubeMX Specific Parameters (not defined in opt.h) ---------------------*/
/* Parameters set in STM32CubeMX LwIP Configuration GUI -*/
/*----- WITH_RTOS enabled (Since FREERTOS is set) -----*/
#define WITH_RTOS 1
/*----- CHECKSUM_BY_HARDWARE disabled -----*/
#define CHECKSUM_BY_HARDWARE 0
/*-----------------------------------------------------------------------------*/

/* LwIP Stack Parameters (modified compared to initialization value in opt.h) -*/
/* Parameters set in STM32CubeMX LwIP Configuration GUI -*/
/*----- Value in opt.h for MEM_ALIGNMENT: 1 -----*/
#define MEM_ALIGNMENT 4
/*----- Default Value for MEMP_NUM_TCP_SEG: 16 ---*/
#define MEMP_NUM_TCP_SEG 24
/*----- Value in opt.h for LWIP_ETHERNET: LWIP_ARP || PPPOE_SUPPORT -*/
#define LWIP_ETHERNET 1
/*----- Value in opt.h for LWIP_DNS_SECURE: (LWIP_DNS_SECURE_RAND_XID | LWIP_DNS_SECURE_NO_MULTIPLE_OUTSTANDING | LWIP_DNS_SECURE_RAND_SRC_PORT) -*/
#define LWIP_DNS_SECURE 7
/*----- Default Value for TCP_SND_BUF: 1072 ---*/
#define TCP_SND_BUF 1840
/*----- Default Value for TCP_SND_QUEUELEN: 15 ---*/
#define TCP_SND_QUEUELEN 17
/*----- Value in opt.h for TCP_WND_UPDATE_THRESHOLD: LWIP_MIN(TCP_WND/4, TCP_MSS*4) -----*/
#define TCP_WND_UPDATE_THRESHOLD 536
/*----- Value in opt.h for TCPIP_THREAD_STACKSIZE: 0 -----*/
#define TCPIP_THREAD_STACKSIZE 1024
/*----- Value in opt.h for TCPIP_THREAD_PRIO: 1 -----*/
#define TCPIP_THREAD_PRIO 3
/*----- Value in opt.h for TCPIP_MBOX_SIZE: 0 -----*/
#define TCPIP_MBOX_SIZE 6
/*----- Value in opt.h for SLIPIF_THREAD_STACKSIZE: 0 -----*/
#define SLIPIF_THREAD_STACKSIZE 1024
/*----- Value in opt.h for SLIPIF_THREAD_PRIO: 1 -----*/
#define SLIPIF_THREAD_PRIO 3
/*----- Value in opt.h for DEFAULT_THREAD_STACKSIZE: 0 -----*/
#define DEFAULT_THREAD_STACKSIZE 1024
/*----- Value in opt.h for DEFAULT_THREAD_PRIO: 1 -----*/
#define DEFAULT_THREAD_PRIO 3
/*----- Value in opt.h for DEFAULT_UDP_RECVMBOX_SIZE: 0 -----*/
#define DEFAULT_UDP_RECVMBOX_SIZE 6
/*----- Value in opt.h for DEFAULT_TCP_RECVMBOX_SIZE: 0 -----*/
#define DEFAULT_TCP_RECVMBOX_SIZE 6
/*----- Value in opt.h for DEFAULT_ACCEPTMBOX_SIZE: 0 -----*/
#define DEFAULT_ACCEPTMBOX_SIZE 6
/*----- Value in opt.h for RECV_BUFSIZE_DEFAULT: INT_MAX -----*/
#define RECV_BUFSIZE_DEFAULT 2000000000
/*----- Value in opt.h for LWIP_STATS: 1 -----*/
#define LWIP_STATS 0
/*----- Value in opt.h for CHECKSUM_GEN_IP: 1 -----*/
#define CHECKSUM_GEN_IP 0
/*----- Value in opt.h for CHECKSUM_GEN_UDP: 1 -----*/
#define CHECKSUM_GEN_UDP 0
/*----- Value in opt.h for CHECKSUM_GEN_TCP: 1 -----*/
#define CHECKSUM_GEN_TCP 0
/*----- Value in opt.h for CHECKSUM_GEN_ICMP: 1 -----*/
#define CHECKSUM_GEN_ICMP 0
/*----- Value in opt.h for CHECKSUM_GEN_ICMP6: 1 -----*/
#define CHECKSUM_GEN_ICMP6 0
/*----- Value in opt.h for CHECKSUM_CHECK_IP: 1 -----*/
#define CHECKSUM_CHECK_IP 0
/*----- Value in opt.h for CHECKSUM_CHECK_UDP: 1 -----*/
#define CHECKSUM_CHECK_UDP 0
/*----- Value in opt.h for CHECKSUM_CHECK_TCP: 1 -----*/
#define CHECKSUM_CHECK_TCP 0
/*----- Value in opt.h for CHECKSUM_CHECK_ICMP: 1 -----*/
#define CHECKSUM_CHECK_ICMP 0
/*----- Value in opt.h for CHECKSUM_CHECK_ICMP6: 1 -----*/
#define CHECKSUM_CHECK_ICMP6 0
/*-----------------------------------------------------------------------------*/
#ifdef __cplusplus
}
#endif
#endif /*__LWIPOPTS__H__ */

/************************* (C) COPYRIGHT STMicroelectronics *****END OF FILE****/

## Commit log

2019-03-25 Added docker-compose support.
    TODO: socket.io not working
2019-03-25 feat: socket listener service
2019-04-01 feat: serial asyncio + zmq serial_port-socket_server tested.
2019-06-16 init: hw files added
    Altium base-board template added
    [Sheet1.SchDoc, base-board.PrjPcb, dwm.SchDoc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]
2019-06-16 chore: rename dirs
    [Sheet1.SchDoc, base-board.PrjPcb, dwm.SchDoc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]
2019-06-17 wip: added hw docs, schematic in progress
    [AUDIO.SchDoc, Arduino_ Connectors.SchDoc, Connectors.SchDoc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]
2019-06-17 wip: schematic in work
    [MB1137.PrjPCB, MCU_144.SchDoc, PoE.SchDoc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]
2019-06-23 feat: net config, socket protocol, some shit
    fix before tsk_udp remake
    [main.cpp]
2019-06-23 feat: nucleo<->server udp works!
    - udpClient recv/send threads
    - .md protocol
2019-06-27 wip: sch
    [base-board.PrjPcb, base-board.SchDoc, dwm.SchDoc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]
2019-06-28 work: schematics
    [base-board.SchDoc]
2019-07-09 work: sch
    [dwm.SchDoc, ethernet.SchDoc, mcu.SchDoc]
2019-07-14 work: sch, pcb
    [base-board.PrjPcb, base-board.SchDoc, base-board_v0.PcbDoc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]
2019-07-16 work: pcb
    [base-board.PrjPcb, base-board.SchDoc, base-board_v0.PcbDoc]
2019-07-18 work: pcb, components placed
    [base-board_v0.PcbDoc, ethernet.SchDoc]
2019-07-31 Revert "work: pcb"
    [base-board.PrjPcb, base-board.SchDoc, base-board_v0.PcbDoc]
2019-08-05 work: pcb base board v1
    [base-board.PrjPcb, base-board.SchDoc, base-board_v0.PcbDoc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]
2019-10-07 work: base-board-v2
    [LCSC_Exported_20191002_022427.xlsx, LCSC_Exported_20191002_023205.xlsx, base-board.PrjPcb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]
2020-02-18 deca driver files added
2020-02-19 work: porting decawave driver, in process
2020-02-21 work: porting deca driver
2020-05-09 stage. init, resp twr modes. slow work.
2020-07-23 tdoa, fix before new anchors
    [dwm1000.cpp, dwm1000.h, main.cpp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]
2020-07-23 fix before anchor v2
    [main.cpp, tsk_tcp_client.cpp]
2020-07-23 new indication tests (not working)
    [anchor.ioc, dwm1000.cpp, ethernetif.c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]
2020-07-24 hsi, indication dma not working
    [anchor.ioc, indication.cpp, main.c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]
2022-02-24 {!} Clean
    [.custom.cfg, EVK1000_CubeMX.cfg]

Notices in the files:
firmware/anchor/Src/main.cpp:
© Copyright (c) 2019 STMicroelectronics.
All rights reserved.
